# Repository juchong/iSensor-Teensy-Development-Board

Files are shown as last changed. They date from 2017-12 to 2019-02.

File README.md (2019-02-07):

# iSensor Teensy Development Board
### An open source development board for Analog Devices iSensor products

This development board was designed to provide users with an easy way to develop and test firmware using iSensor MEMS IMUs. The board conforms to the standard Arduino pinout making it compatible with the entire ecosystem of break-out boards. A Teensy 3.1, 3.2, or LC may be used with this board, minimizing cost. The board includes a standard 2mm pitch 16 pin connector similar to the BlackFin evaluation board, making all iSensor breakout boards compatible. 

The board includes the following features:
- 4V ~ 20V input, 3.3V output switching regulator with selectable input (USB vs External)
- Programmable high-side switch for controlled switching tests
- 3.3V external supply input
- I2C/Analog Input selectable solder pads
- Compatible with Arduino pinout and mechanical form factor

Note that the switching regulator is optional and does not have to be installed for the breakout board to properly function.

Click here to order a set of boards from OshPark: [https://oshpark.com/shared_projects/IdmggZVF](https://oshpark.com/shared_projects/IdmggZVF)

ADIS16470-Teensy Interface Board

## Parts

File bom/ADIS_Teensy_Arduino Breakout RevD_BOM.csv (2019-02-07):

Qty-1 | Part References | Value | Mfg Part Num | Mfg Name | Vendor Part Num | Description
2 | J10, J7 |  | 68000-103HLF | Amphenol FCI | 609-3461-ND | BERGSTIK II .100"" SR STRAIGHT
2 | C7, C8 | 0.1uF | CL10B104KB8NNNC | Samsung Electro-Mechanics America | 1276-1000-1-ND | CAP CER 0.1UF 50V 10% X7R 0603
1 | R7 | 2.55k | ERJ-3EKF2551V | Panasonic Electronic Components | P2.55KHCT-ND | RES SMD 2.55K OHM 1% 1/10W 0603
1 | J9 | 3V3 EXT | 20020327-C021B01LF | FCI | 609-4725-ND | 3.5MM TERMINAL BLOCK -55~110C
1 | R6 | 10.2k | ERJ-3EKF1022V | Panasonic Electronic Components | P10.2KHCT-ND | RES SMD 10.2K OHM 1% 1/10W 0603
3 | C12, C9, C10 | 22uF | TLJA476M010R0600 | AVX Corporation | 478-9009-1-ND | CAP TANT 47UF 10V 20% 1206
1 | R5 | 31.6k | ERJ-3EKF3162V | Panasonic Electronic Components | P31.6KHCT-ND | RES SMD 31.6K OHM 1% 1/10W 0603
1 | J1 | A3-16PA-2SV(71)T | A3-16PA-2SV(71) | Hirose Electric Co Ltd | H10940-ND | CONN HEADER 16POS 2MM GOLD SMD
1 | U1 | ADP2303 | ADP2303ARDZ | Analog Devices Inc | ADP2303ARDZ-ND | IC REG BUCK ADJ 3A 8SOIC
1 | J4 | AVR_SPI_PRG_6PTH | M20-9720345 | Harwin Inc | 952-1921-ND | 2X3POS DIL VERTICAL PIN HEADER
1 | L1 | CLF6045T-6R8N-H | CLF6045T-6R8N-H | TDK Corporation | 445-15108-1-ND | FIXED IND 6.8UH 2.9A 27 MOHM SMD
1 | J11 | M02PTH | 68000-103HLF | Amphenol FCI | 609-3461-ND | BERGSTIK II .100"" SR STRAIGHT
1 | U2 | SIP32510 | SIP32510DT-T1-GE3 | Vishay Siliconix | SIP32510DT-T1-GE3CT-ND | IC LOAD SWITCH SOT23-6
2 | D1, D2 | SSB43L-E3 | SSB43L-E3/52T | Vishay Semiconductor Diodes Division | SSB43L-E3/52TGICT-ND | DIODE SCHOTTKY 30V 4A DO214AA
1 | J3 |  | TEENSY32 | pjrc.com | TEENSY32 | Teensy USB Board Version 3.2
1 | J8 |  | 20020327-C021B01LF | FCI | 609-4725-ND | 3.5MM TERMINAL BLOCK -55~110C

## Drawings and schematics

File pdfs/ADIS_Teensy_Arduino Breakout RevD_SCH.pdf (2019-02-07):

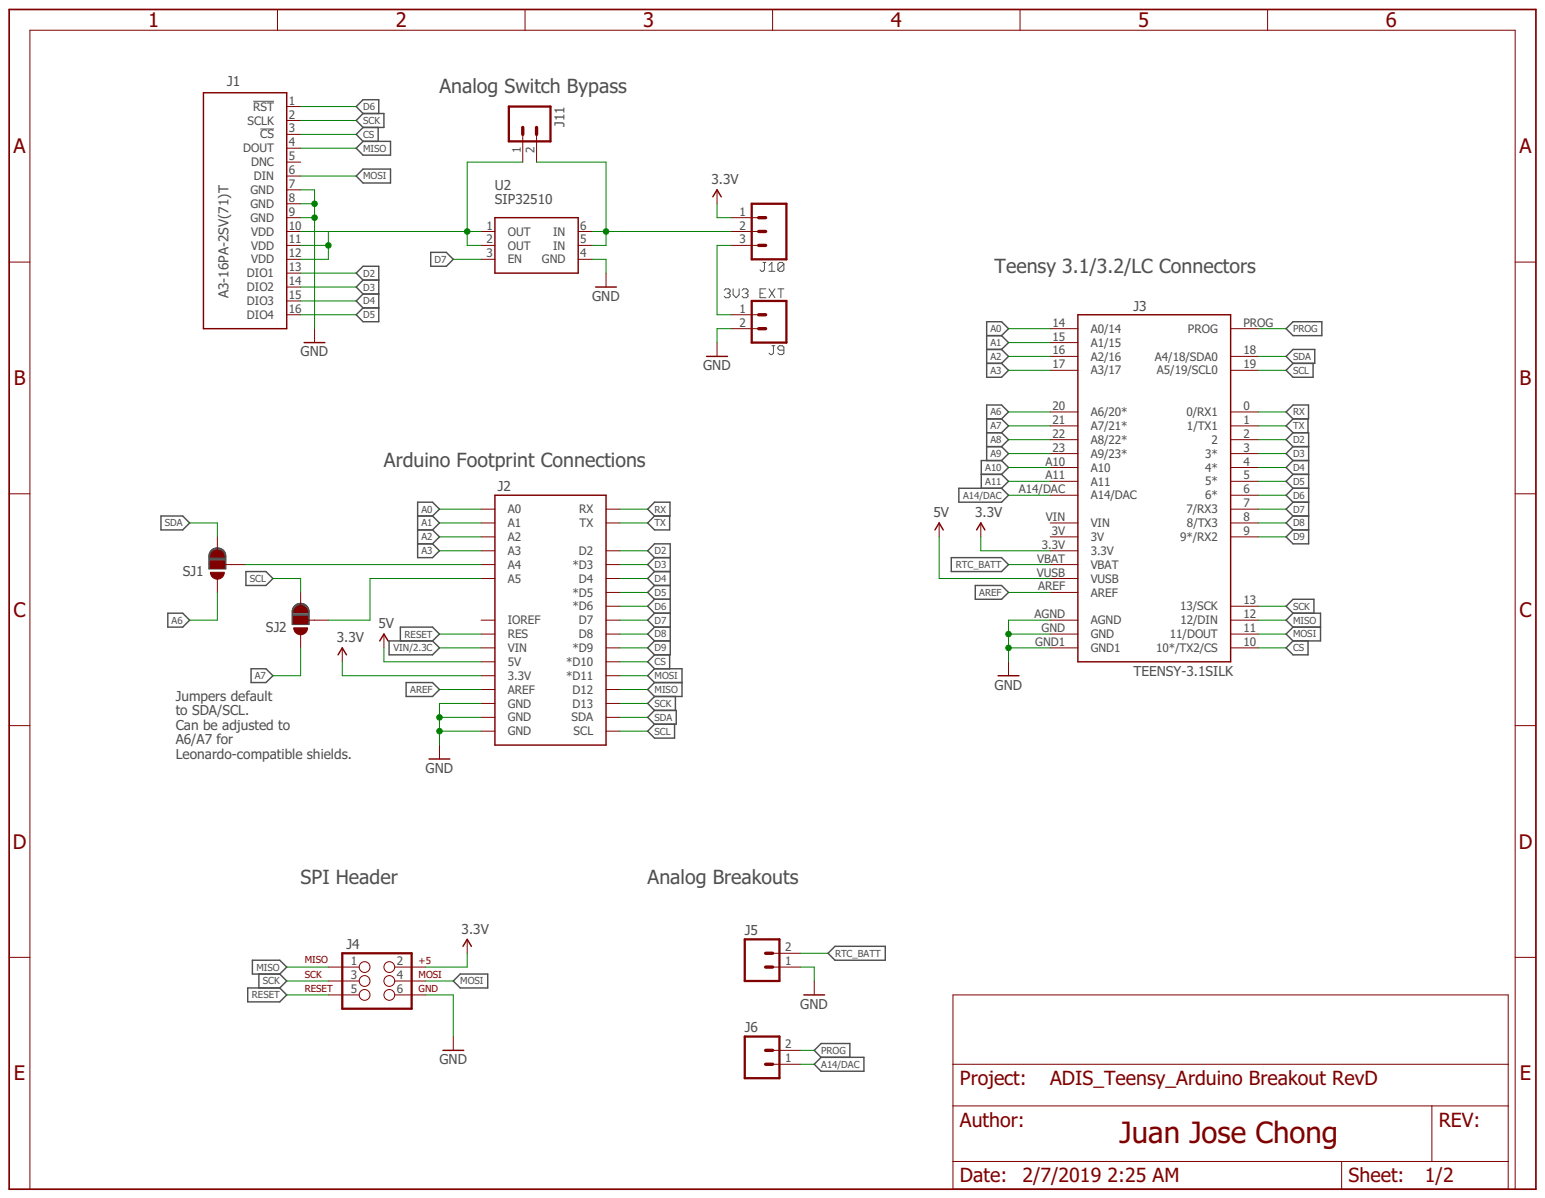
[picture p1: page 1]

Jumpers default
to SDA/SCL. Can be adjusted to A6/A7 for Leonardo-compatible shields.

Author: Juan Jose Chong | REV:

Date: 2/7/2019 2:25 AM | Sheet: 1/2

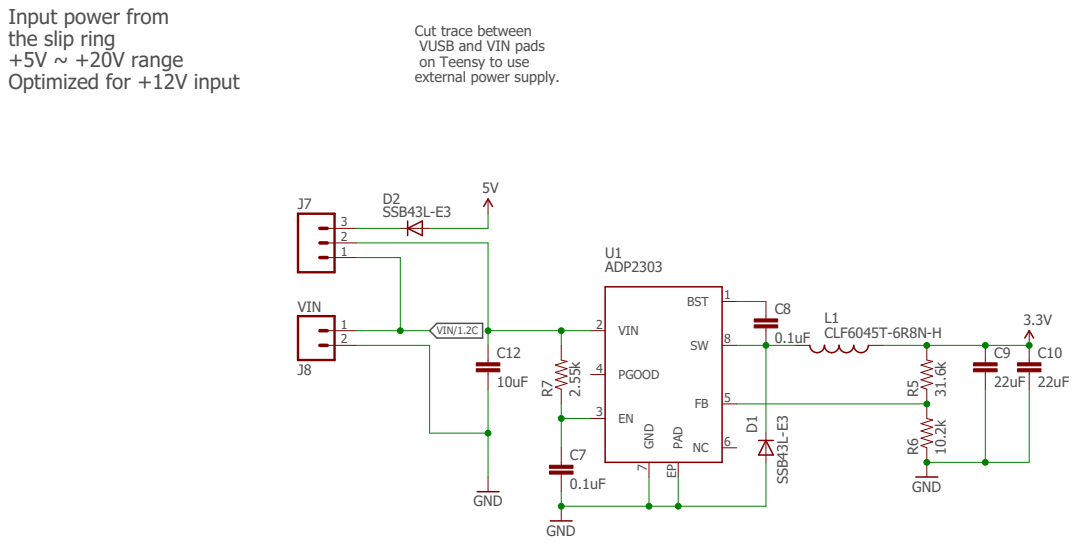
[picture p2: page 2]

Cut trace between VUSB and VIN pads on Teensy to use

Author: Juan Jose Chong | REV:

Date: 2/7/2019 2:25 AM | Sheet: 2/2

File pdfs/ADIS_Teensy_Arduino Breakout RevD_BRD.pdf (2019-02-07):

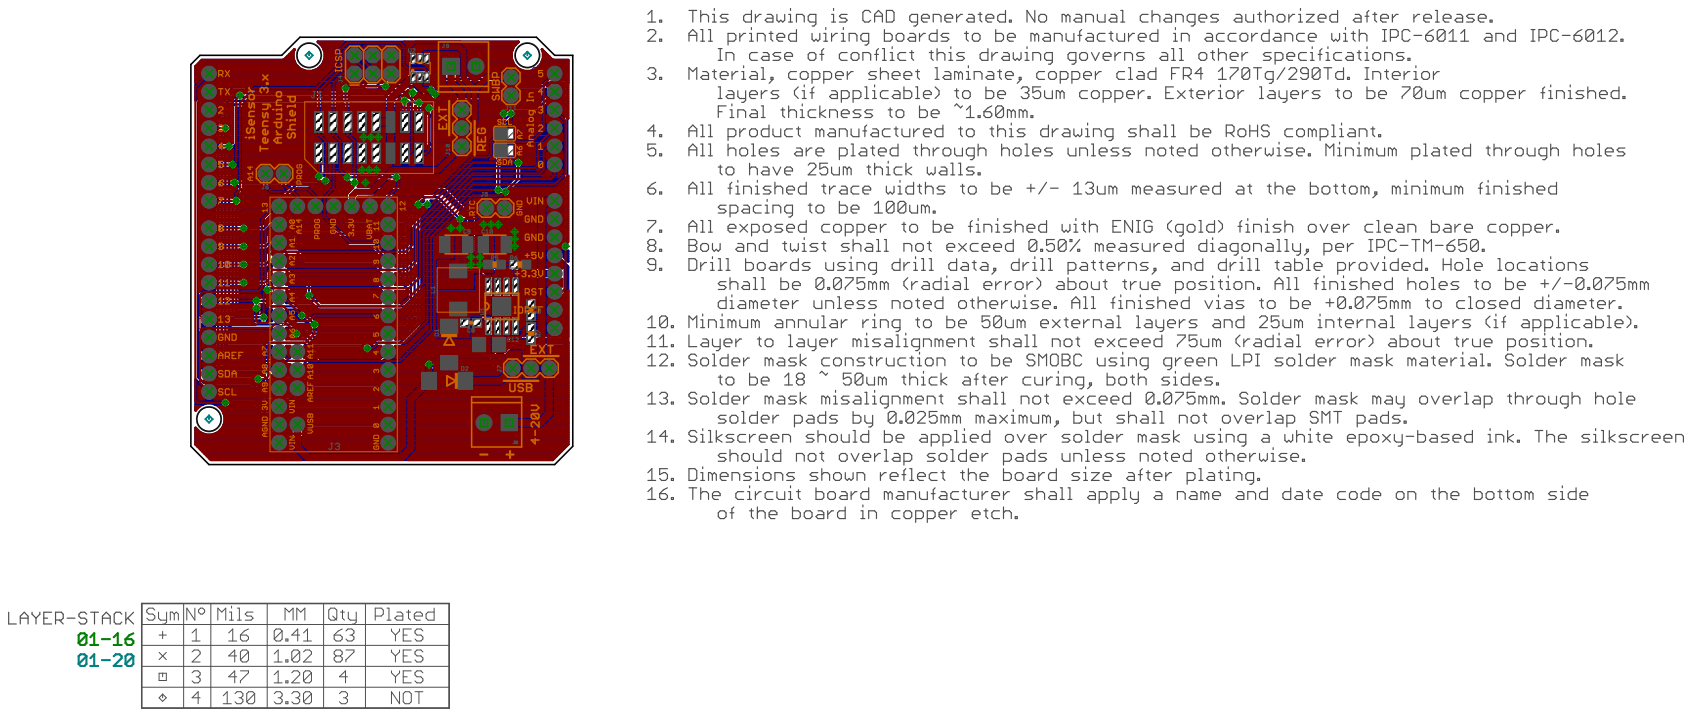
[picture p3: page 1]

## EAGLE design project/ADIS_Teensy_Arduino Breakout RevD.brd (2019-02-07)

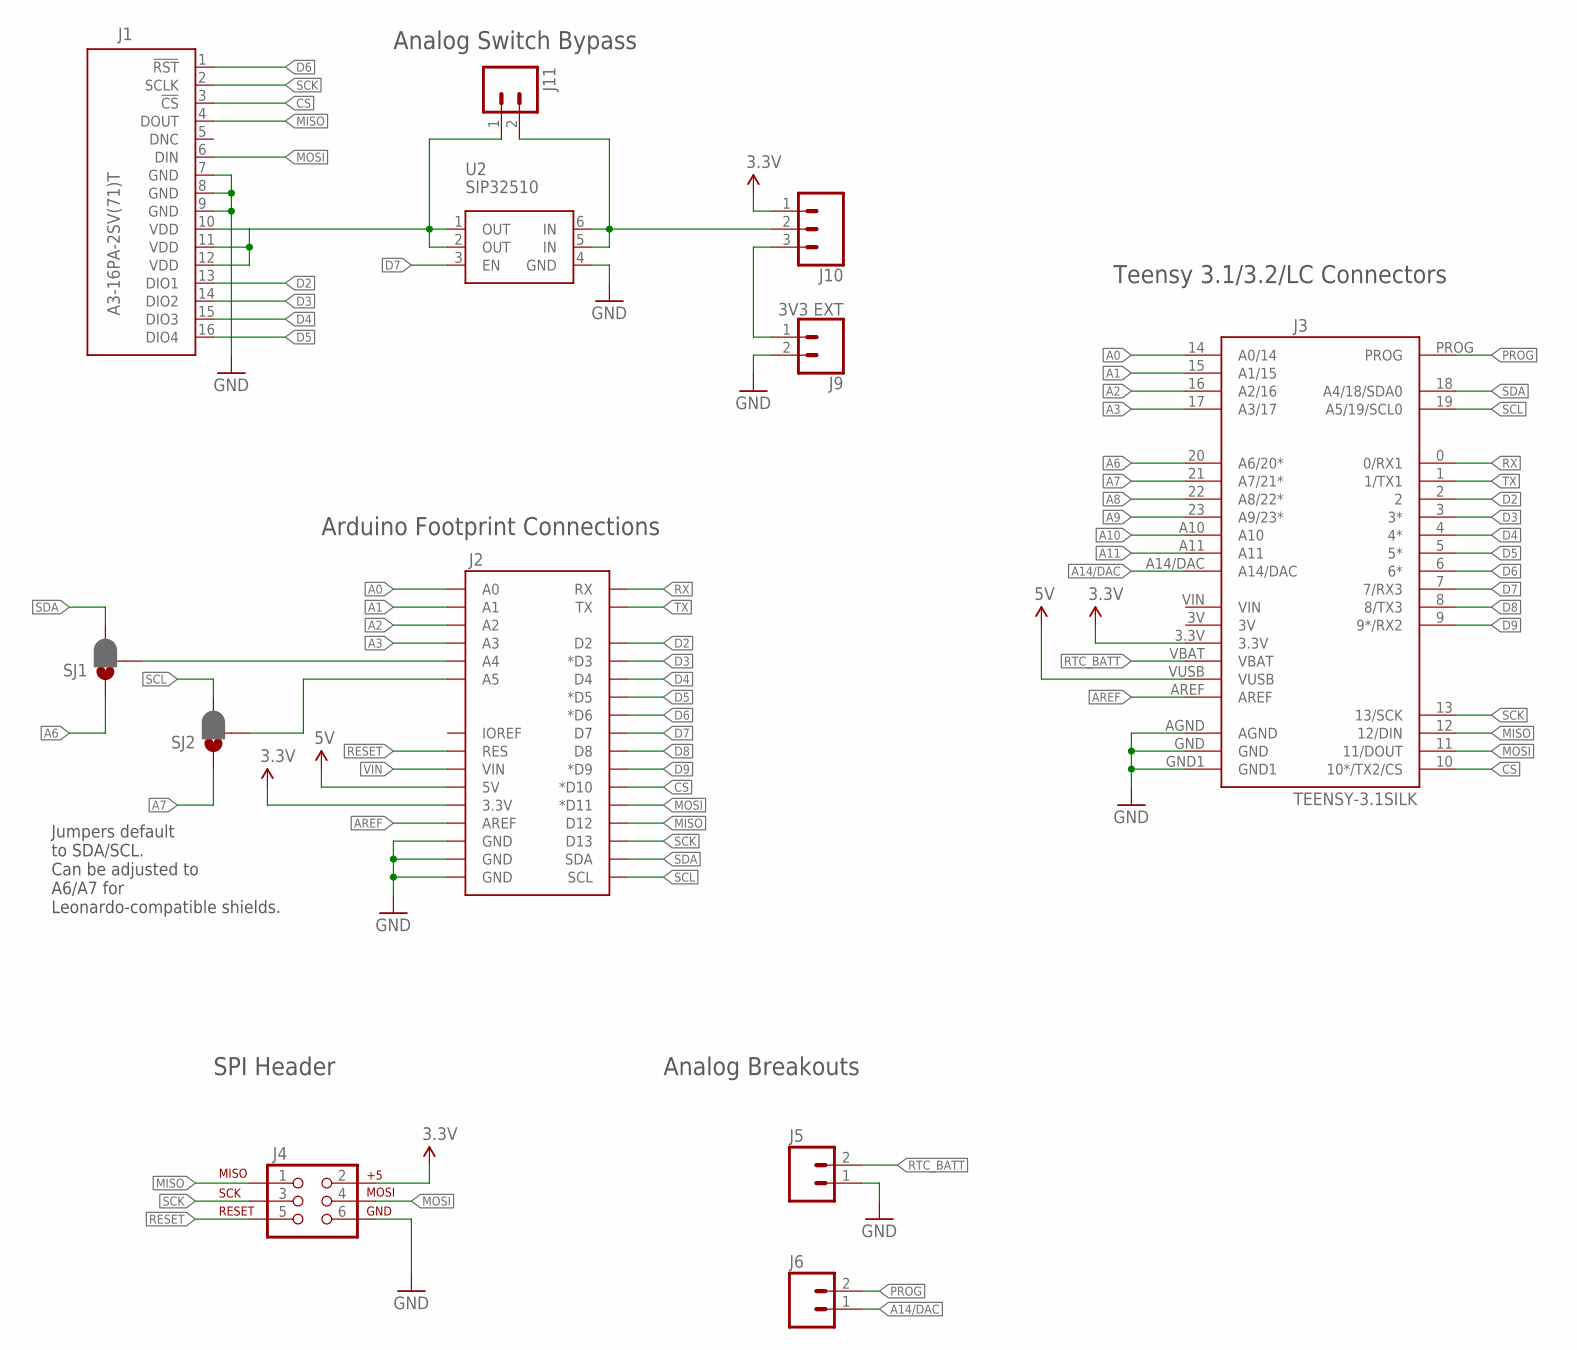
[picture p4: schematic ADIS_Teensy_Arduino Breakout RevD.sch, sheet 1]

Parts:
J1: A3-16PA-2SV(71)T; A3-16PA-2SV(71)-TOP; PARTNO A3-16PA-2SV(71)
J2: ARDUINO_R3_SHIELDUNO_R3_SHIELD_HOLES; UNO_R3_SHIELD_HOLES
J3: TEENSY-3.1SILK; TEENSY-3.1; PARTNO TEENSY32
J4: AVR_SPI_PRG_6PTH; 2X3; PARTNO M20-9720345
J5, J6, J11: M02PTH; 1X02@1
J9: 3V3 EXT; SCREWTERMINAL-3.5MM-2; PARTNO 20020327-C021B01LF
J10: CONN_03; 1X03; PARTNO 68000-103HLF
SJ1, SJ2: JUMPER-PAD-3-2OF3_NC_BY_PASTE; PAD-JUMPER-3-2OF3_NC_BY_PASTE_YES_SILK_FULL_BOX
U2: SIP32510; SOT23-6; PARTNO SIP32510DT-T1-GE3

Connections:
3.3V: J2.3.3V, J3.3.3V, J4.2, J10.1; also elsewhere on the board
5V: J2.5V, J3.VUSB; also elsewhere on the board
A0: J2.A0, J3.14 (A0/14)
A1: J2.A1, J3.15 (A1/15)
A2: J2.A2, J3.16 (A2/16)
A3: J2.A3, J3.17 (A3/17)
A4: J2.A4, SJ1.2
A5: J2.A5, SJ2.2
A6: J3.20 (A6/20*), SJ1.1
A7: J3.21 (A7/21*), SJ2.1
A8: J3.22 (A8/22*)
A9: J3.23 (A9/23*)
A10: J3.A10
A11: J3.A11
A14/DAC: J3.A14/DAC, J6.1
AREF: J2.AREF, J3.AREF
CS: J1.3 (!CS), J2.D10 (*D10), J3.10 (10*/TX2/CS)
D2: J1.13 (DIO1), J2.D2, J3.2
D3: J1.14 (DIO2), J2.D3 (*D3), J3.3 (3*)
D4: J1.15 (DIO3), J2.D4, J3.4 (4*)
D5: J1.16 (DIO4), J2.D5 (*D5), J3.5 (5*)
D6: J1.1 (!RST), J2.D6 (*D6), J3.6 (6*)
D7: J2.D7, J3.7 (7/RX3), U2.3 (EN)
D8: J2.D8, J3.8 (8/TX3)
D9: J2.D9 (*D9), J3.9 (9*/RX2)
GND: J1.7 (GND), J1.8 (GND), J1.9 (GND), J2.GND@0 (GND), J2.GND@1 (GND), J2.GND@2 (GND), J3.AGND, J3.GND, J3.GND1, J4.6, J5.1, J9.2, U2.4 (GND); also elsewhere on the board
MISO: J1.4 (DOUT), J2.D12, J3.12 (12/DIN), J4.1
MOSI: J1.6 (DIN), J2.D11 (*D11), J3.11 (11/DOUT), J4.4
unnamed: J1.10 (VDD), J1.11 (VDD), J1.12 (VDD), J11.1, U2.1 (OUT), U2.2 (OUT)
unnamed: J9.1, J10.3
unnamed: J10.2, J11.2, U2.5 (IN), U2.6 (IN)
PROG: J3.PROG, J6.2
RESET: J2.RES, J4.5
RTC_BATT: J3.VBAT, J5.2
RX: J2.RX, J3.0 (0/RX1)
SCK: J1.2 (SCLK), J2.D13, J3.13 (13/SCK), J4.3
SCL: J2.SCL, J3.19 (A5/19/SCL0), SJ2.3
SDA: J2.SDA, J3.18 (A4/18/SDA0), SJ1.3
TX: J2.TX, J3.1 (1/TX1)
VIN: J2.VIN; also elsewhere on the board

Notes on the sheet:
Jumpers default to SDA/SCL. Can be adjusted to A6/A7 for Leonardo-compatible shields.
Arduino Footprint Connections
SPI Header
Analog Breakouts
Teensy 3.1/3.2/LC Connectors
Analog Switch Bypass

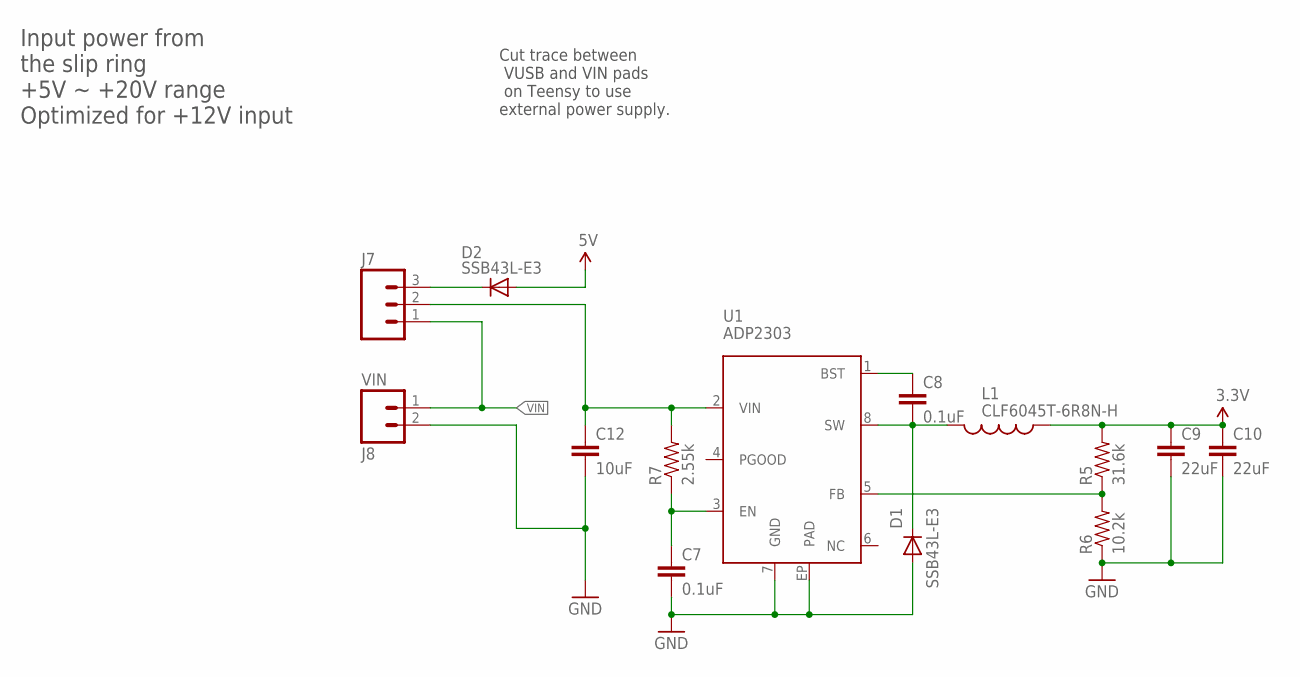
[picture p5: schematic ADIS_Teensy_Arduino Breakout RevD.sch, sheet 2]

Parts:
C7, C8: 0.1uF; 0603-CAP; PARTNO CL10B104KB8NNNC
C9, C10: 22uF; 1210; PARTNO TLJA476M010R0600
C12: 10uF; 1206; PARTNO TLJA476M010R0600
D1, D2: SSB43L-E3; DO214AA; PARTNO SSB43L-E3/52T
J7: M03PTH; 1X03@1; PARTNO 68000-103HLF
J8: VIN; SCREWTERMINAL-3.5MM-2@1; PARTNO 20020327-C021B01LF
L1: CLF6045T-6R8N-H; CLF6045-H; PARTNO CLF6045T-6R8N-H
R5: 31.6k; 0603-RES; PARTNO ERJ-3EKF3162V
R6: 10.2k; 0603-RES; PARTNO ERJ-3EKF1022V
R7: 2.55k; 0603-RES; PARTNO ERJ-3EKF2551V
U1: ADP2303; SOIC-8-PAD; PARTNO ADP2303ARDZ

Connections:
3.3V: C9.1, C10.1, L1.P$1 (1), R5.2; also elsewhere on the board
5V: D2.A; also elsewhere on the board
GND: C7.2, C9.2, C10.2, C12.2, D1.A, J8.2, R6.1, U1.7 (GND), U1.EP (PAD); also elsewhere on the board
unnamed: R5.1, R6.2, U1.5 (FB)
unnamed: C8.2, D1.C, L1.P$2 (2), U1.8 (SW)
unnamed: C8.1, U1.1 (BST)
unnamed: C7.1, R7.1, U1.3 (EN)
unnamed: C12.1, J7.2, R7.2, U1.2 (VIN)
unnamed: D2.C, J7.3
VIN: J7.1, J8.1; also elsewhere on the board

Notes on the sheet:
Input power from the slip ring +5V ~ +20V range Optimized for +12V input
Cut trace between VUSB and VIN pads on Teensy to use external power supply.

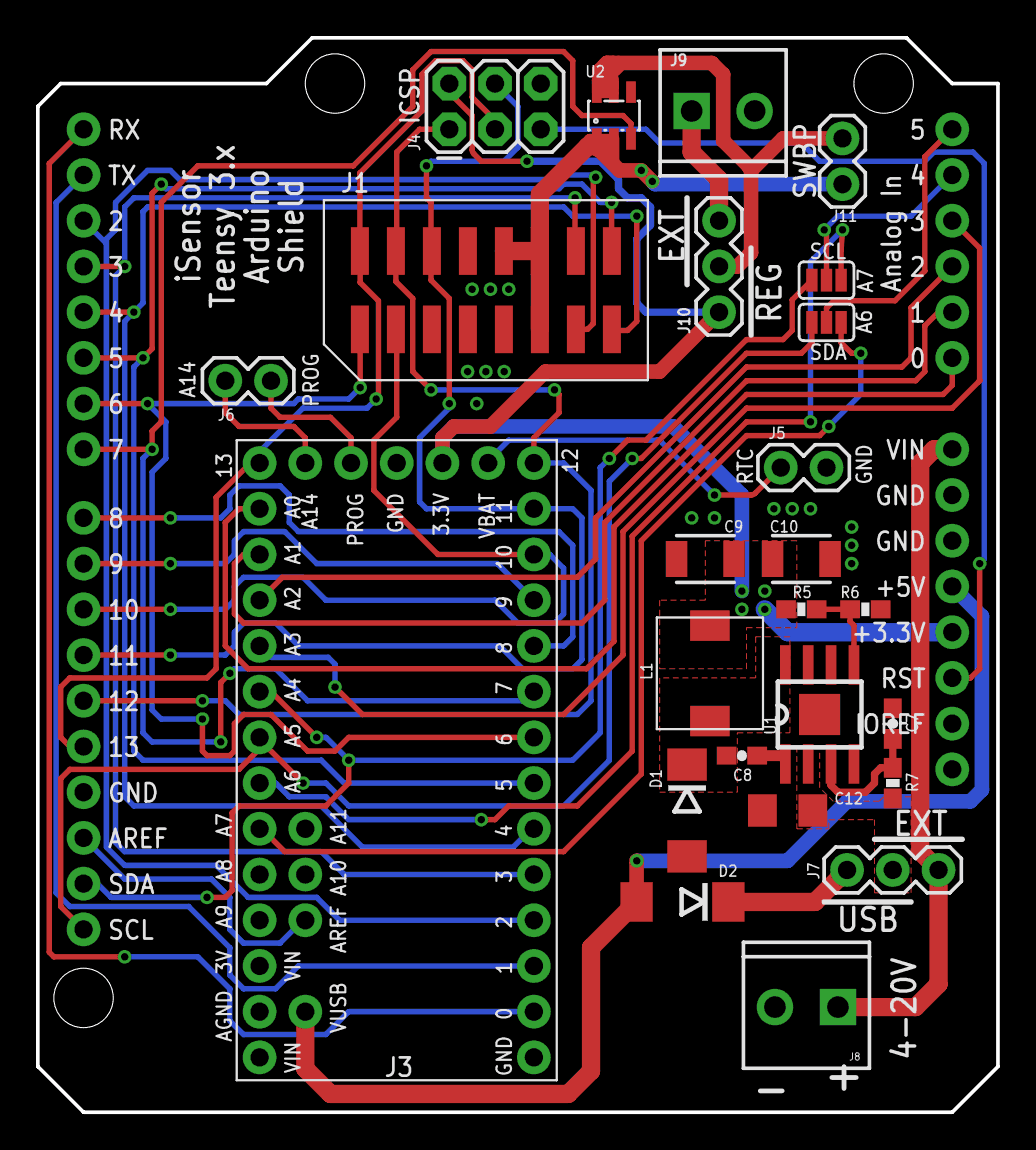
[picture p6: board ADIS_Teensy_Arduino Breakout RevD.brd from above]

Board: 2 copper layers, 53.3 x 59.7 mm, 26 parts (0 on the bottom side), 42 nets.

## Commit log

2017-12-20 Initial Rev C commit
    [ADIS Teensy Arduino Breakout RevA.brd, ADIS Teensy Arduino Breakout RevA.sch, ADIS Teensy Arduino Breakout RevB.brd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]
2017-12-20 Updated BOM in brd and sch files
    [ADIS Teensy Arduino Breakout RevC.brd, ADIS Teensy Arduino Breakout RevC.sch]
2019-02-07 Updated PCB to Rev D
    [ADIS Teensy Arduino Breakout RevA.brd, ADIS Teensy Arduino Breakout RevA.sch, ADIS Teensy Arduino Breakout RevC BOM.csv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]
2019-02-07 Updated Readme with new PCB link

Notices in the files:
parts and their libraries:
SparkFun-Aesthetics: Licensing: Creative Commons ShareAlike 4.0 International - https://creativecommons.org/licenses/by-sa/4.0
